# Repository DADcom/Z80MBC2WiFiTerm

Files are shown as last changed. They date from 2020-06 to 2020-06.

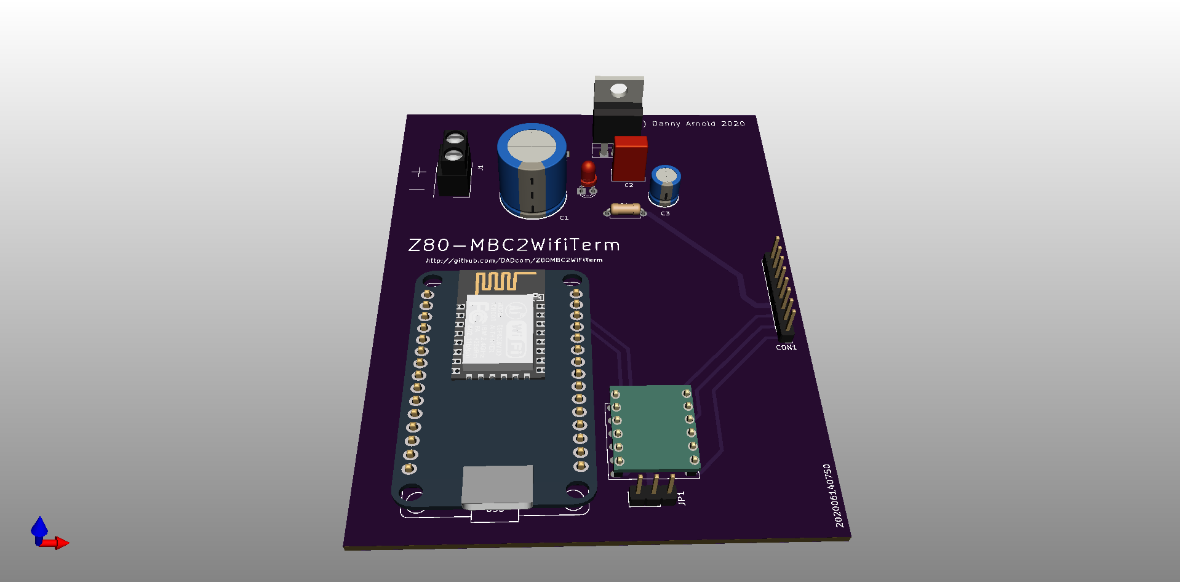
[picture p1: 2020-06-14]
images/WifiTerm.png

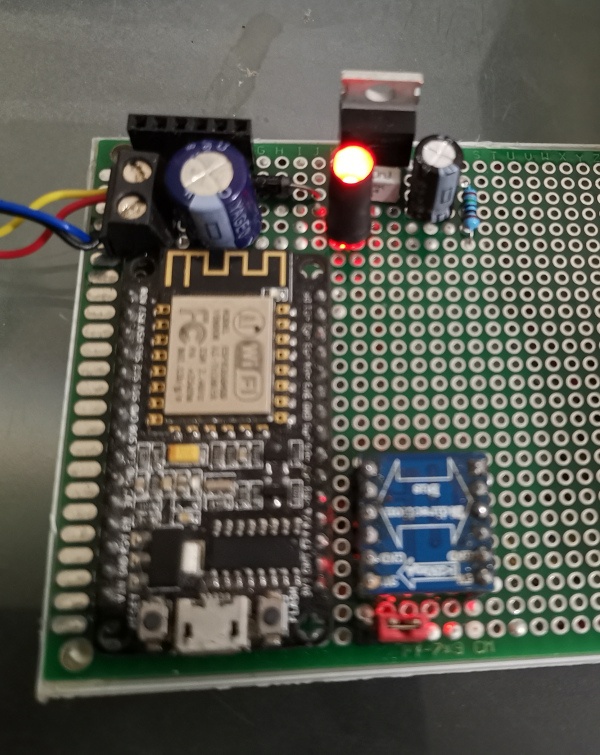
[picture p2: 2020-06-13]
images/esp8266.jpg

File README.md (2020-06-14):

Remote WiFi Terminal for Z80-MBC2
=================================

A mashup of WifiTerm for Arduino ESP 8266
and xterm.js for a Wi-Fi addon to the Z80-MBC2 
released under MIT

please see the license

 (C) Danny Arnold 2020
 Portions of this code are 
 Copyright (c) 2020 bricoleau
 Copyright (c) 2017-2019, The xterm.js authors (MIT License)
 Copyright (c) 2014-2017, SourceLair, Private Company (www.sourcelair.com) (MIT License)
 Copyright (c) 2012-2013, Christopher Jeffrey (MIT License)

Please see Releases for current release
https://github.com/DADcom/Z80MBC2WiFiTerm/releases

To-do

- Implement 'user' key support - requires updating Z80-MBC2 firmware for support
- Documentation finish documentation wiki
- ~~Kicad schematics of ESP8266 implementation~~

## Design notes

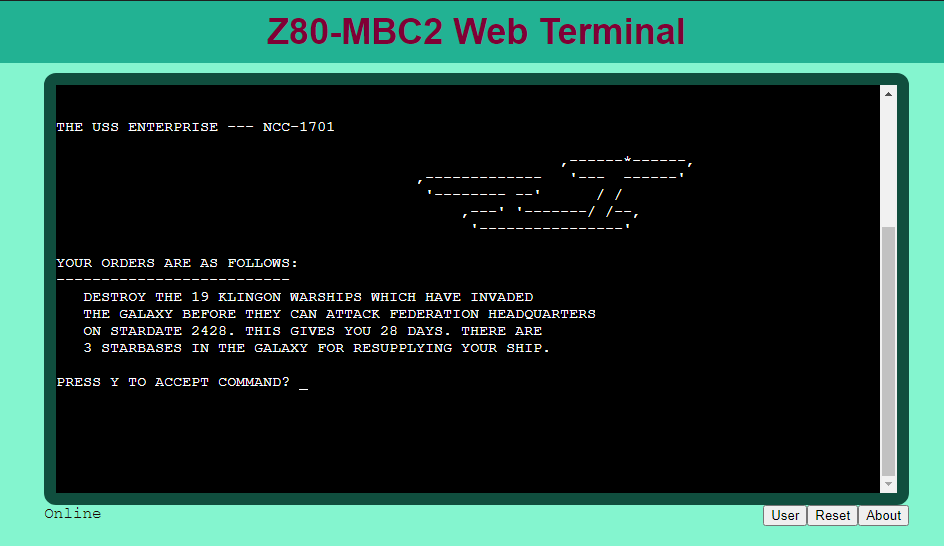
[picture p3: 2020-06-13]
images/screenshot2.png

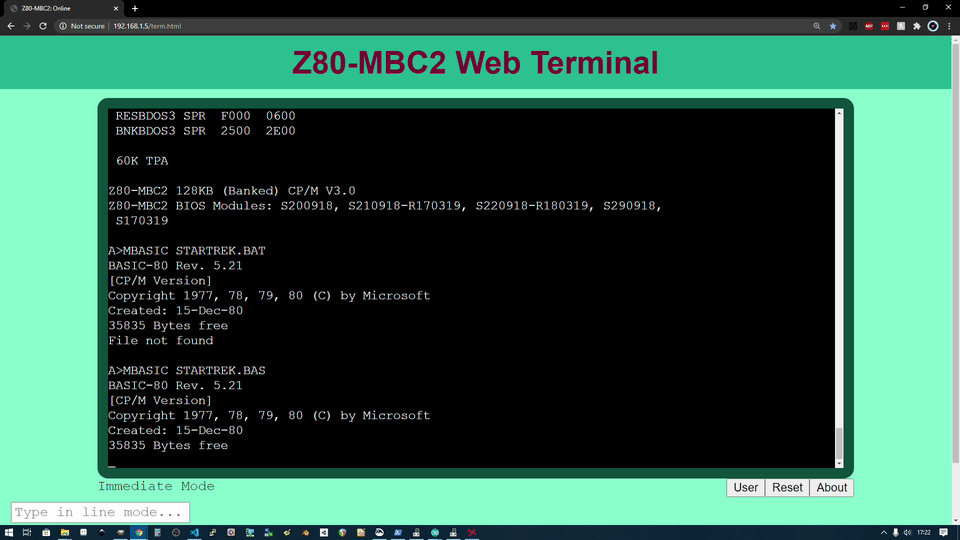
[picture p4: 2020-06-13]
images/InstantGif_2020.06.13-17.22.gif

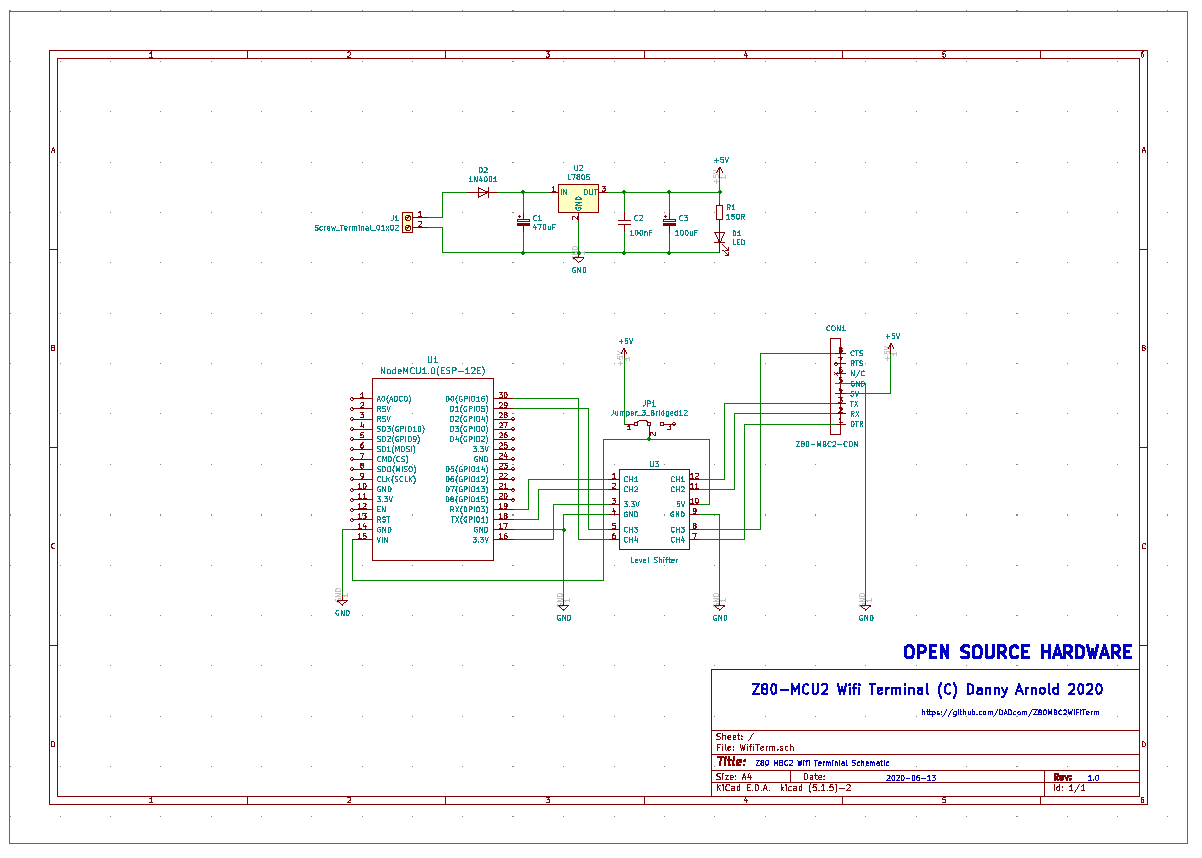
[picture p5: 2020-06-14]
images/schmatic capture.png

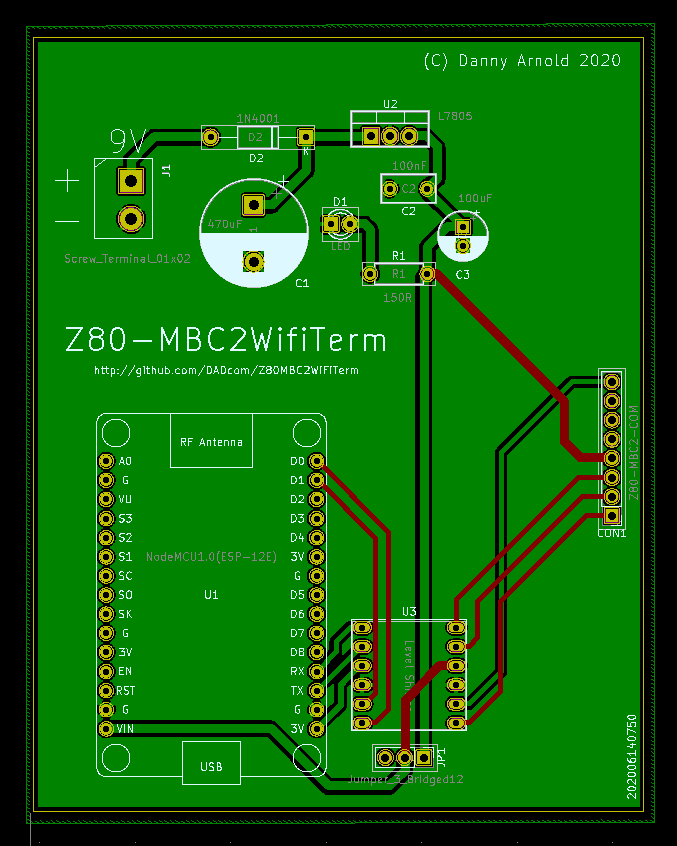
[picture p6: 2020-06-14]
images/PCB.png

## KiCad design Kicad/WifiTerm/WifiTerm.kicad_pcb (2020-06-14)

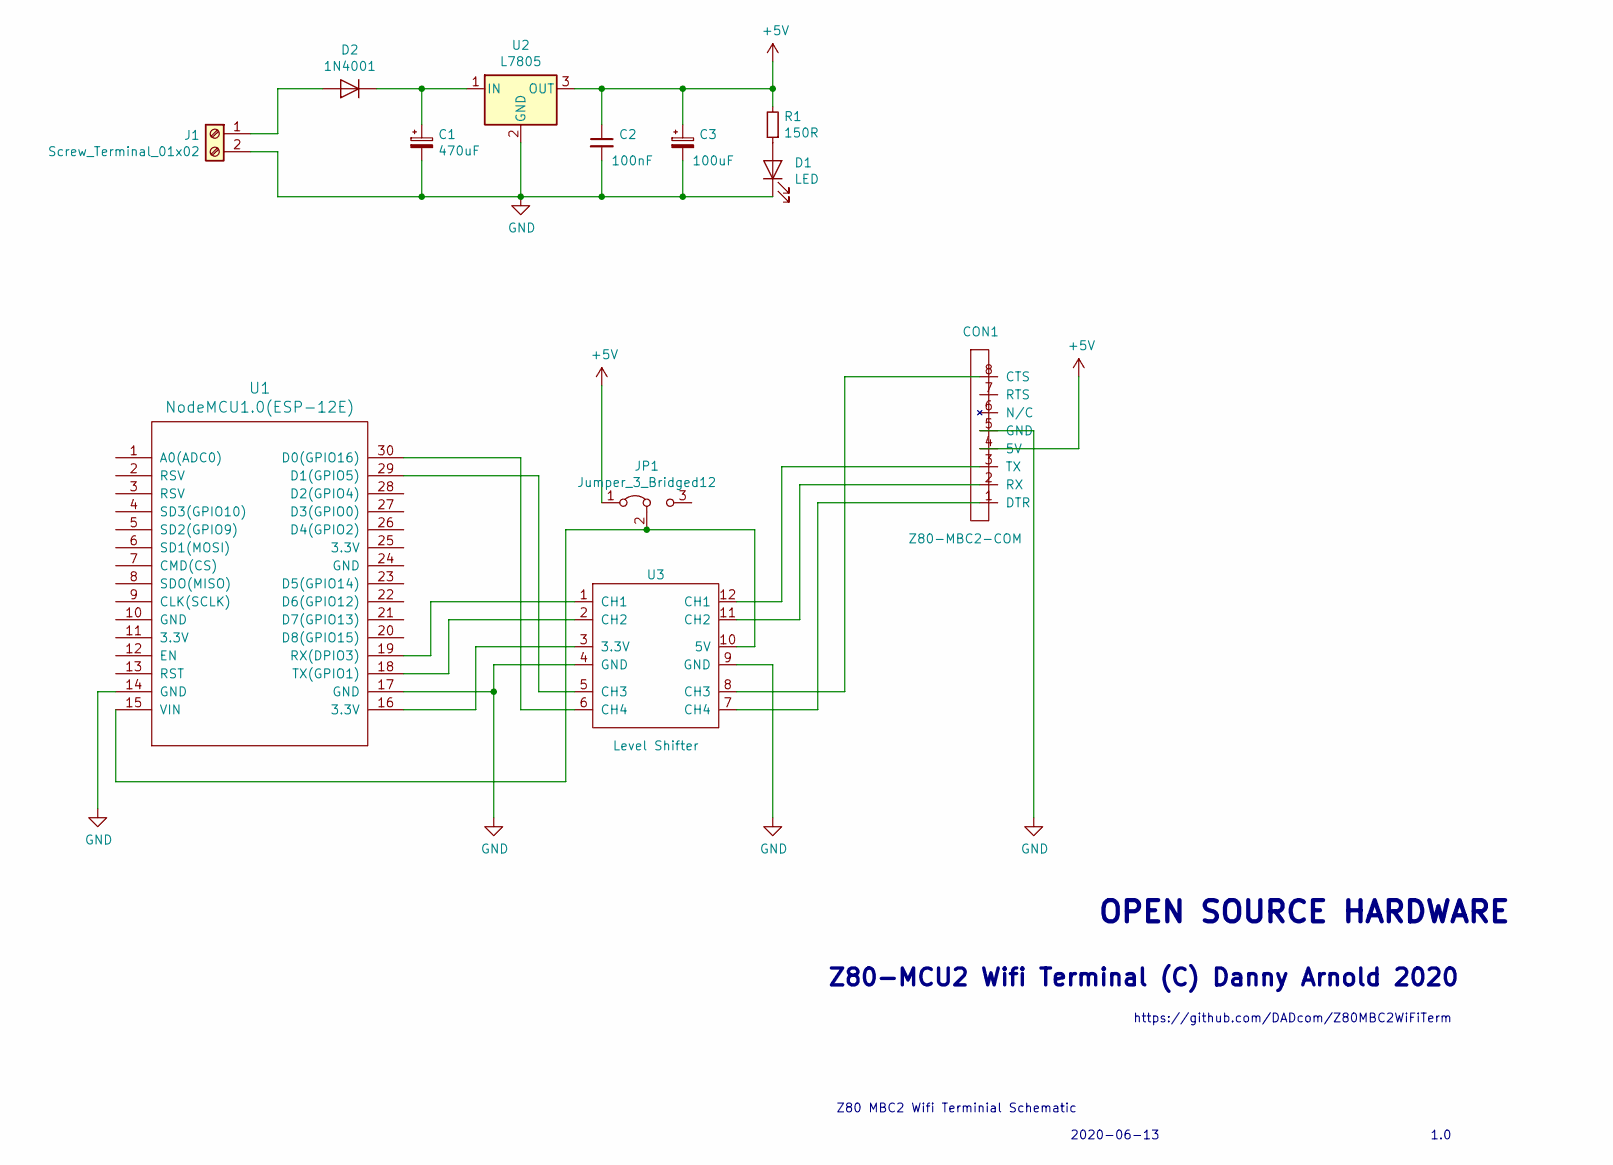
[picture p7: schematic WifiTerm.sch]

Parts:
C1: 470uF; CP_Radial_D14.0mm_P7.50mm
C2: 100nF; C_Rect_L7.0mm_W3.5mm_P5.00mm
C3: 100uF; CP_Radial_D6.3mm_P2.50mm
CON1: Z80-MBC2-COM; PinHeader_1x08_P2.54mm_Vertical
D1: LED; LED_D3.0mm
D2: 1N4001; D_A-405_P12.70mm_Horizontal
J1: Screw_Terminal_01x02; ScrewTerm1x02_P5.00mm
JP1: Jumper_3_Bridged12; PinHeader_1x03_P2.54mm_Vertical
R1: 150R; R_Axial_DIN0207_L6.3mm_D2.5mm_P7.62mm_Horizontal
U1: NodeMCU1.0(ESP-12E); NodeMCU1.0(12-E)
U2: L7805; TO-220-3_Vertical
U3: Level Shifter; LogicLevelShift

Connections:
+5V: C2.1, C3.1, CON1.4 (5V), JP1.1 (A), R1.2, U2.3 (OUT)
GND: C1.2, C2.2, C3.2, CON1.5 (GND), D1.1 (K), J1.2, U1.14 (GND), U1.17 (GND), U2.2 (GND), U3.4 (GND), U3.9 (GND)
unnamed: C1.1, D2.1 (K), U2.1 (IN)
unnamed: CON1.1 (DTR), U3.7 (CH4)
unnamed: CON1.2 (RX), U3.11 (CH2)
unnamed: CON1.3 (TX), U3.12 (CH1)
unnamed: CON1.8 (CTS), U3.8 (CH3)
unnamed: D1.2 (A), R1.1
unnamed: D2.2 (A), J1.1
unnamed: JP1.2 (C), U1.15 (VIN), U3.10 (5V)
unnamed: U1.16 (3.3V), U3.3 (3.3V)
unnamed: U1.18 (TX(GPIO1)), U3.2 (CH2)
unnamed: U1.19 (RX(DPIO3)), U3.1 (CH1)
unnamed: U1.29 (D1(GPIO5)), U3.5 (CH3)
unnamed: U1.30 (D0(GPIO16)), U3.6 (CH4)

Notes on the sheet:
Z80-MCU2 Wifi Terminal (C) Danny Arnold 2020
OPEN SOURCE HARDWARE
Z80 MBC2 Wifi Terminial Schematic
2020-06-13
1.0
https://github.com/DADcom/Z80MBC2WiFiTerm

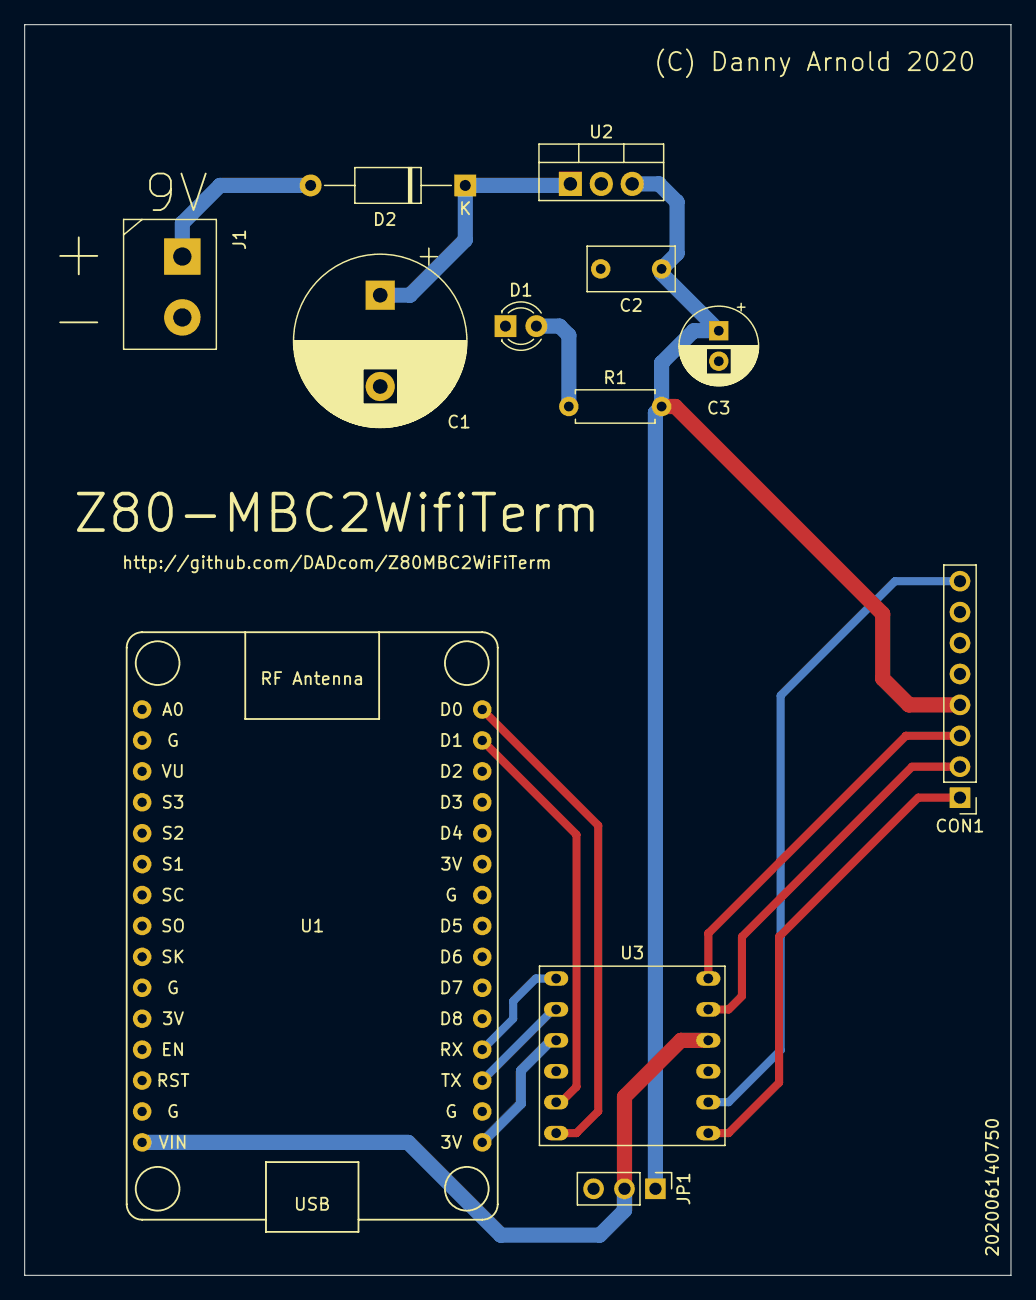
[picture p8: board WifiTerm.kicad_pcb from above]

Board: 2 copper layers, 81.0 x 102.7 mm, 12 parts (0 on the bottom side), 15 nets.

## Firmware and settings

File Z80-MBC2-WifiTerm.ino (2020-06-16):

/**
 * Z80MBC2WifiTerm 
 * 
 * (C) Danny Arnold 2020
 * Portions of this code are 
 * Copyright (c) 2020 bricoleau
 * Copyright (c) 2017-2019, The xterm.js authors (MIT License)
 * Copyright (c) 2014-2017, SourceLair, Private Company (www.sourcelair.com) (MIT License)
 * Copyright (c) 2012-2013, Christopher Jeffrey (MIT License)
 * 
 * License MIT
 *  
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
 * The above copyright notice and this permission notice shall be included in all copies or substantial portions of the Software.
 * 
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
 * 
 * */

#include <ESP8266WiFi.h>
#include "private.h"
#include "WiFiTerm.h"

ESP8266WebServer server(80);

uint8_t timeout_ms = 1;
String buf = "";
int loc = 0;
bool delsup = false;
void setup()
{
  pinMode(LED_BUILTIN, OUTPUT);
  pinMode(D0, OUTPUT);
  pinMode(D1, OUTPUT);
  digitalWrite(D0, HIGH);
  digitalWrite(D1, LOW);
  WiFi.begin(ssid, password);
  while (WiFi.status() != WL_CONNECTED)
  {
    delay(250);
    digitalWrite(LED_BUILTIN, LOW);
    delay(250);
    digitalWrite(LED_BUILTIN, HIGH);
  }

  server.begin();
  term.begin(server);
  Serial.begin(115200);
  term.print("Z80-MBC2 Connected..");
  term.println();
  reset();
}

void loop()
{
  server.handleClient();
  term.handleClient();
  if (term.available())
  {
    buf = term.readString();

    if (buf == "+++ATH0" ){
        reset();
        buf = "";
      }
    else if (buf == "+++ATH1"){
        setUser(false);
        buf = "";
    }
    else if (buf == "+++ATH2"){
        setUser(true);
        buf = "";
    }else Serial.print(buf);
    
  }
  size_t qty = WIFITERM_TX_BUF_SIZE;
  while (Serial.available() && qty--)
  {
    char c = Serial.read();
    term.print(c);
    if (!Serial.available()){
      delay(timeout_ms); //wait for next char
    }
  }
}
void reset(){
  digitalWrite(D0, LOW);
  delay(50);
  digitalWrite(D0, HIGH);   
}
void setUser(bool usr){
  if (usr) digitalWrite(D1, HIGH);
  else digitalWrite(D1, LOW);
}
